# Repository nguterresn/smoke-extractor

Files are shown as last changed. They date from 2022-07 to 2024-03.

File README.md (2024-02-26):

# Welcome to the Smoke Extractor Repository!

Are you tired of inhaling smoke and fumes while soldering? Look no further! This portable smoke extractor is here to evolve your soldering experience.

This repository contains all the information you need to build your own smoke extractor using readily available components.

| [PCB](https://github.com/nguterresn/smoke-extractor/tree/master/pcb/1v1) | [STL](https://github.com/nguterresn/smoke-extractor/tree/master/stl) | [GERBER](https://github.com/nguterresn/smoke-extractor/blob/master/pcb/1v1/jlcpcb/production_files/GERBER-smoke_extractorV1_1.zip) | [BOM](https://github.com/nguterresn/smoke-extractor/blob/master/pcb/1v1/jlcpcb/production_files/BOM-smoke_extractorV1_1.csv) |
|-----|-----|---|-----|

Below is a list of what you need. Let's start with the PCB:

* Take the [Bill of Materials](https://github.com/nguterresn/smoke-extractor/blob/master/pcb/1v1/jlcpcb/production_files/BOM-smoke_extractorV1_1.csv) and order from [LCSC](https://www.lcsc.com).
* Take the [compressed gerber files](https://github.com/nguterresn/smoke-extractor/blob/master/pcb/1v1/jlcpcb/production_files/GERBER-smoke_extractorV1_1.zip) and order the PCB from [JLCPCB](https://jlcpcb.com)

To 3D print the [enclosure](https://github.com/nguterresn/smoke-extractor/tree/master/stl/1v1), I would recommend to print it vertically with supports only where the PCB fits and at the top.

* You can find the files for the enclosure at [Thinginverse](https://www.thingiverse.com/thing:6496883) or on the [repository](https://github.com/nguterresn/smoke-extractor/tree/master/stl/1v1).
* You can find the sliced model and ready to print file for BambuLab printers here.

And finally, necessary items you can find in Amazon:

* Buy the Fume's filter. I took a [filter used on cat litter boxes](https://www.amazon.se/gp/product/B07WJ1Y1CH/ref=ppx_yo_dt_b_asin_title_o08_s00?ie=UTF8&psc=1) and trimmed it to 80x80mm.
* Buy a [80x80x25mm 12V fan](https://www.amazon.se/-/en/1-06W-80x80x25mm-56-1m³-2600U-EE80251S31000U999/dp/B07ZBNZQ2S/ref=sr_1_3?crid=MVLR8KCZBU2A&dib=eyJ2IjoiMSJ9.yyIoiUBXEqPdx7PXhLvxQ6DgrM7XN99XWWnRf-wjLIC2jV-B3UQ4XywT_NGIYMAKHvOpfRhJtW1-Edui-ORV4xDNA9OV7_BThwgb9X33OIwgTvXAGk9CamoQANMFjjYQfQlXwd1fQ9uBfTSz37shrT1HXBxxIDawscOyjEqbqhflptzGCS32OoU-07Krv_tXsq_2aFJ8kRP7iFG2Fm3--l_kvcWPGcEGKE2OmgzGbOBmr5wPGlOs1hTMt8ZC6lYbEhc1kAilJPhcBsXh4ESUahyO5wKTHMeF1VTbrVZGBB4.kkiZ6oj-aX831UgWn2JdLQOQZ6zxw4aFCHIgBYpVpvM&dib_tag=se&keywords=fan+80x80+12v&qid=1708787756&sprefix=fan+80x80+12v%2Caps%2C92&sr=8-3). Any fan should suffice (as long as is within 80x80x25mm), however some fans are specially built for increased air flow and low noise, such as [Noctua ones](https://www.amazon.se/-/en/Noctua-NF-R8-Redux-1800-PWM-performance/dp/B00KF7MVI2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).
* Buy a [18350 battery holder from Amazon](https://www.amazon.se/-/en/3-7V-18650-Battery-Plastic-Storage/dp/B07MM1NHHL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).

Once you have received everything you ordered, I recommend to use an hot air gun or a soldering plate to solder the PCB.

After the soldering process, I recommended soldering the fan power cables into the 12V and GND pads on the PCB, such that the fan is left connected to the PCB.

Start by adding the fan into the top part and match with the bottom pins.
Place the PCB; use two M3-5mm screws to fix it if the PCB is loose.

The cables are hidden below the fan and behind the PCB.

To assemble the back lid you will also need 2x M3-5mm screws and 2x M3-10mm screws.

Happy soldering!

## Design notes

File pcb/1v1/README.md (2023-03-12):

On *CustomSymbols* - Project based symbols.

On *CustomFootprints* - Project based `.kicad_mod` footprints.

On *CustomSteps* - Project based `.step` files.

---

To add symbols to the project, open the file *CustomSymbols* (extension `.kicad_sym`) with a text editor and add the desired symbol as:

```md
(symbol "RA11131100" (in_bom yes) (on_board yes)
    (property "Reference" "U" (id 0) (at 0 0 0)
      (effects (font (size 1.27 1.27)))
    )
    (property "Value" "RA11131100" (id 1) (at 0 0 0)
      (effects (font (size 1.27 1.27)))
    )
    (property "Footprint" "" (id 2) (at 0 0 0)
      (effects (font (size 1.27 1.27)) hide)
    )
    (property "Datasheet" "" (id 3) (at 0 0 0)
      (effects (font (size 1.27 1.27)) hide)
    )
    (symbol "RA11131100_0_1"
      (rectangle (start -3.81 7.62) (end 3.81 2.54)
        (stroke (width 0.1524) (type default) (color 0 0 0 0))
        (fill (type none))
      )
      (arc (start -1.27 6.35) (mid -0.7022 5.0464) (end 0 3.81)
        (stroke (width 0.1524) (type default) (color 0 0 0 0))
        (fill (type none))
      )
    )
    (symbol "RA11131100_1_1"
      (pin power_in line (at -6.35 5.08 0) (length 2.54)
        (name "IN" (effects (font (size 1.27 1.27))))
        (number "1" (effects (font (size 1.27 1.27))))
      )
      (pin power_out line (at 6.35 5.08 180) (length 2.54)
        (name "OUT" (effects (font (size 1.27 1.27))))
        (number "2" (effects (font (size 1.27 1.27))))
      )
    )
)
``` 

The file `sym-lib-table` routes the project to the *CustomSymbols* folder.

---

To add footprints to the project, open the folder *CustomFootprints* and paste the desired `.kicad_mod` file.

The file `fp-lib-table` routes the project to the *CustomFootprints* folder.

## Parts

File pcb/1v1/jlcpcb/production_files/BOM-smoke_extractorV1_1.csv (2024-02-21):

Comment | Designator | Footprint | LCSC
4k7 | R13 | R_0603_1608Metric_Pad0.98x0.95mm_HandSolder | C105428
1.2k | R16 | R_0603_1608Metric_Pad0.98x0.95mm_HandSolder | C118396
TP4056 | U5 | SOP-8_3.9x4.9mm_P1.27mm | C16581
100 | R20 | R_0805_2012Metric_Pad1.20x1.40mm_HandSolder | C17408
5k1 | R10,R2,R22,R9 | R_0603_1608Metric_Pad0.98x0.95mm_HandSolder | C178023
Fuse | F1 | Fuse_0603_1608Metric_Pad1.05x0.95mm_HandSolder | C182303
10u | C6 | C_0603_1608Metric_Pad1.08x0.95mm_HandSolder | C19702
USB-TYPE-C-31-M-15 | U1 | USB-TYPE-C-31-M-15 | C223908
44.2k | R21 | R_0603_1608Metric_Pad0.98x0.95mm_HandSolder | C23056
ME2149FM5G | U7 | SOT-23-5_HandSoldering | C236786
SS14 | D10,D5 | D_SMA | C2480
FH8205 | U8 | SOT-23-6_Handsoldering | C2928988
3.3u | L1 | L_Wuerth_WE-PD2-Typ-MS | C2929417
10k | R5 | R_0603_1608Metric_Pad0.98x0.95mm_HandSolder | C2930027
3k3 | R1,R11,R12,R14,R15,R18,R7,R8 | R_0603_1608Metric_Pad0.98x0.95mm_HandSolder | C3017726
0.1u | C1,C2,C7 | C_0603_1608Metric_Pad1.08x0.95mm_HandSolder | C30926
1k | R3,R4,R6 | R_0603_1608Metric_Pad0.98x0.95mm_HandSolder | C328340
DW01A | IC1 | SOT-23-6_Handsoldering | C351410
SDDJE | U2 | SDDJE | C358626
FDN336P | Q1 | SOT-23 | C475693
LM324DT | U3 | SOIC127P600X175-14N | C71035
22u | C8 | C_0805_2012Metric_Pad1.18x1.45mm_HandSolder | C98190
TestPoint | TP2 | TestPoint_Pad_2.0x2.0mm
MountingHole_Pad | H2 | MountingHole_3.2mm_M3_ISO7380_Pad
YLED | D2 | LED_0603_1608Metric_Pad1.05x0.95mm_HandSolder
LED | D1 | LED_0603_1608Metric_Pad1.05x0.95mm_HandSolder
RLED | D7 | LED_0603_1608Metric_Pad1.05x0.95mm_HandSolder
GLED | D3 | LED_0603_1608Metric_Pad1.05x0.95mm_HandSolder
RLED | D9 | LED_0603_1608Metric_Pad1.05x0.95mm_HandSolder
MountingHole_Pad | H1 | MountingHole_3.2mm_M3_ISO7380_Pad
GLED | D8 | LED_0603_1608Metric_Pad1.05x0.95mm_HandSolder
SW_Push | SW1 | SW_PUSH_6mm
GLED | D4 | LED_0603_1608Metric_Pad1.05x0.95mm_HandSolder
Conn_01x01_Socket | J2 | TestPoint_Pad_2.5x2.5mm
Conn_01x01_Socket | J1 | TestPoint_Pad_2.5x2.5mm
18350-HOLDER | U6 | 18350-Holder

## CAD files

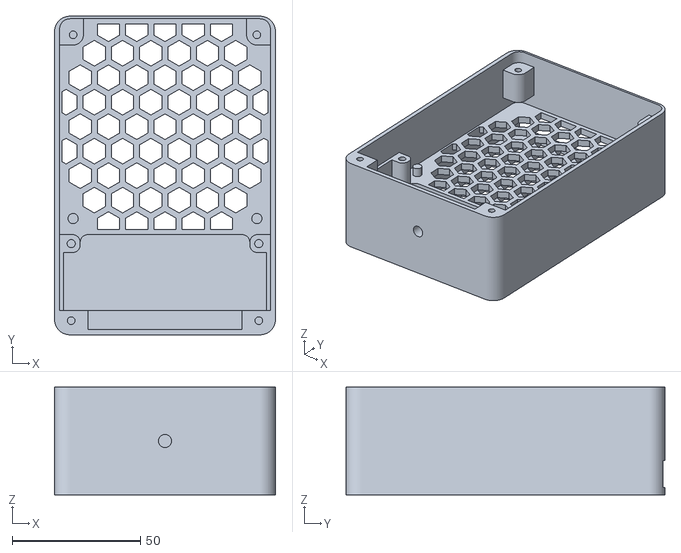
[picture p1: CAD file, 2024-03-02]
stl/Front.stl
86.0 x 124.0 x 42.0

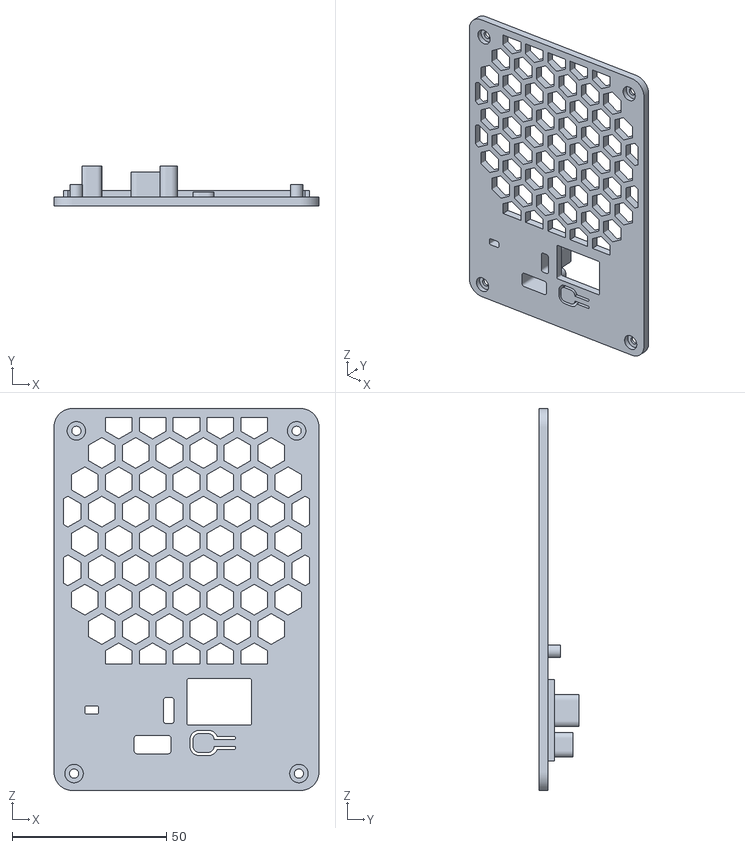
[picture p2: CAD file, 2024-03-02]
stl/BackLid.stl
86.0 x 13.0 x 124.0

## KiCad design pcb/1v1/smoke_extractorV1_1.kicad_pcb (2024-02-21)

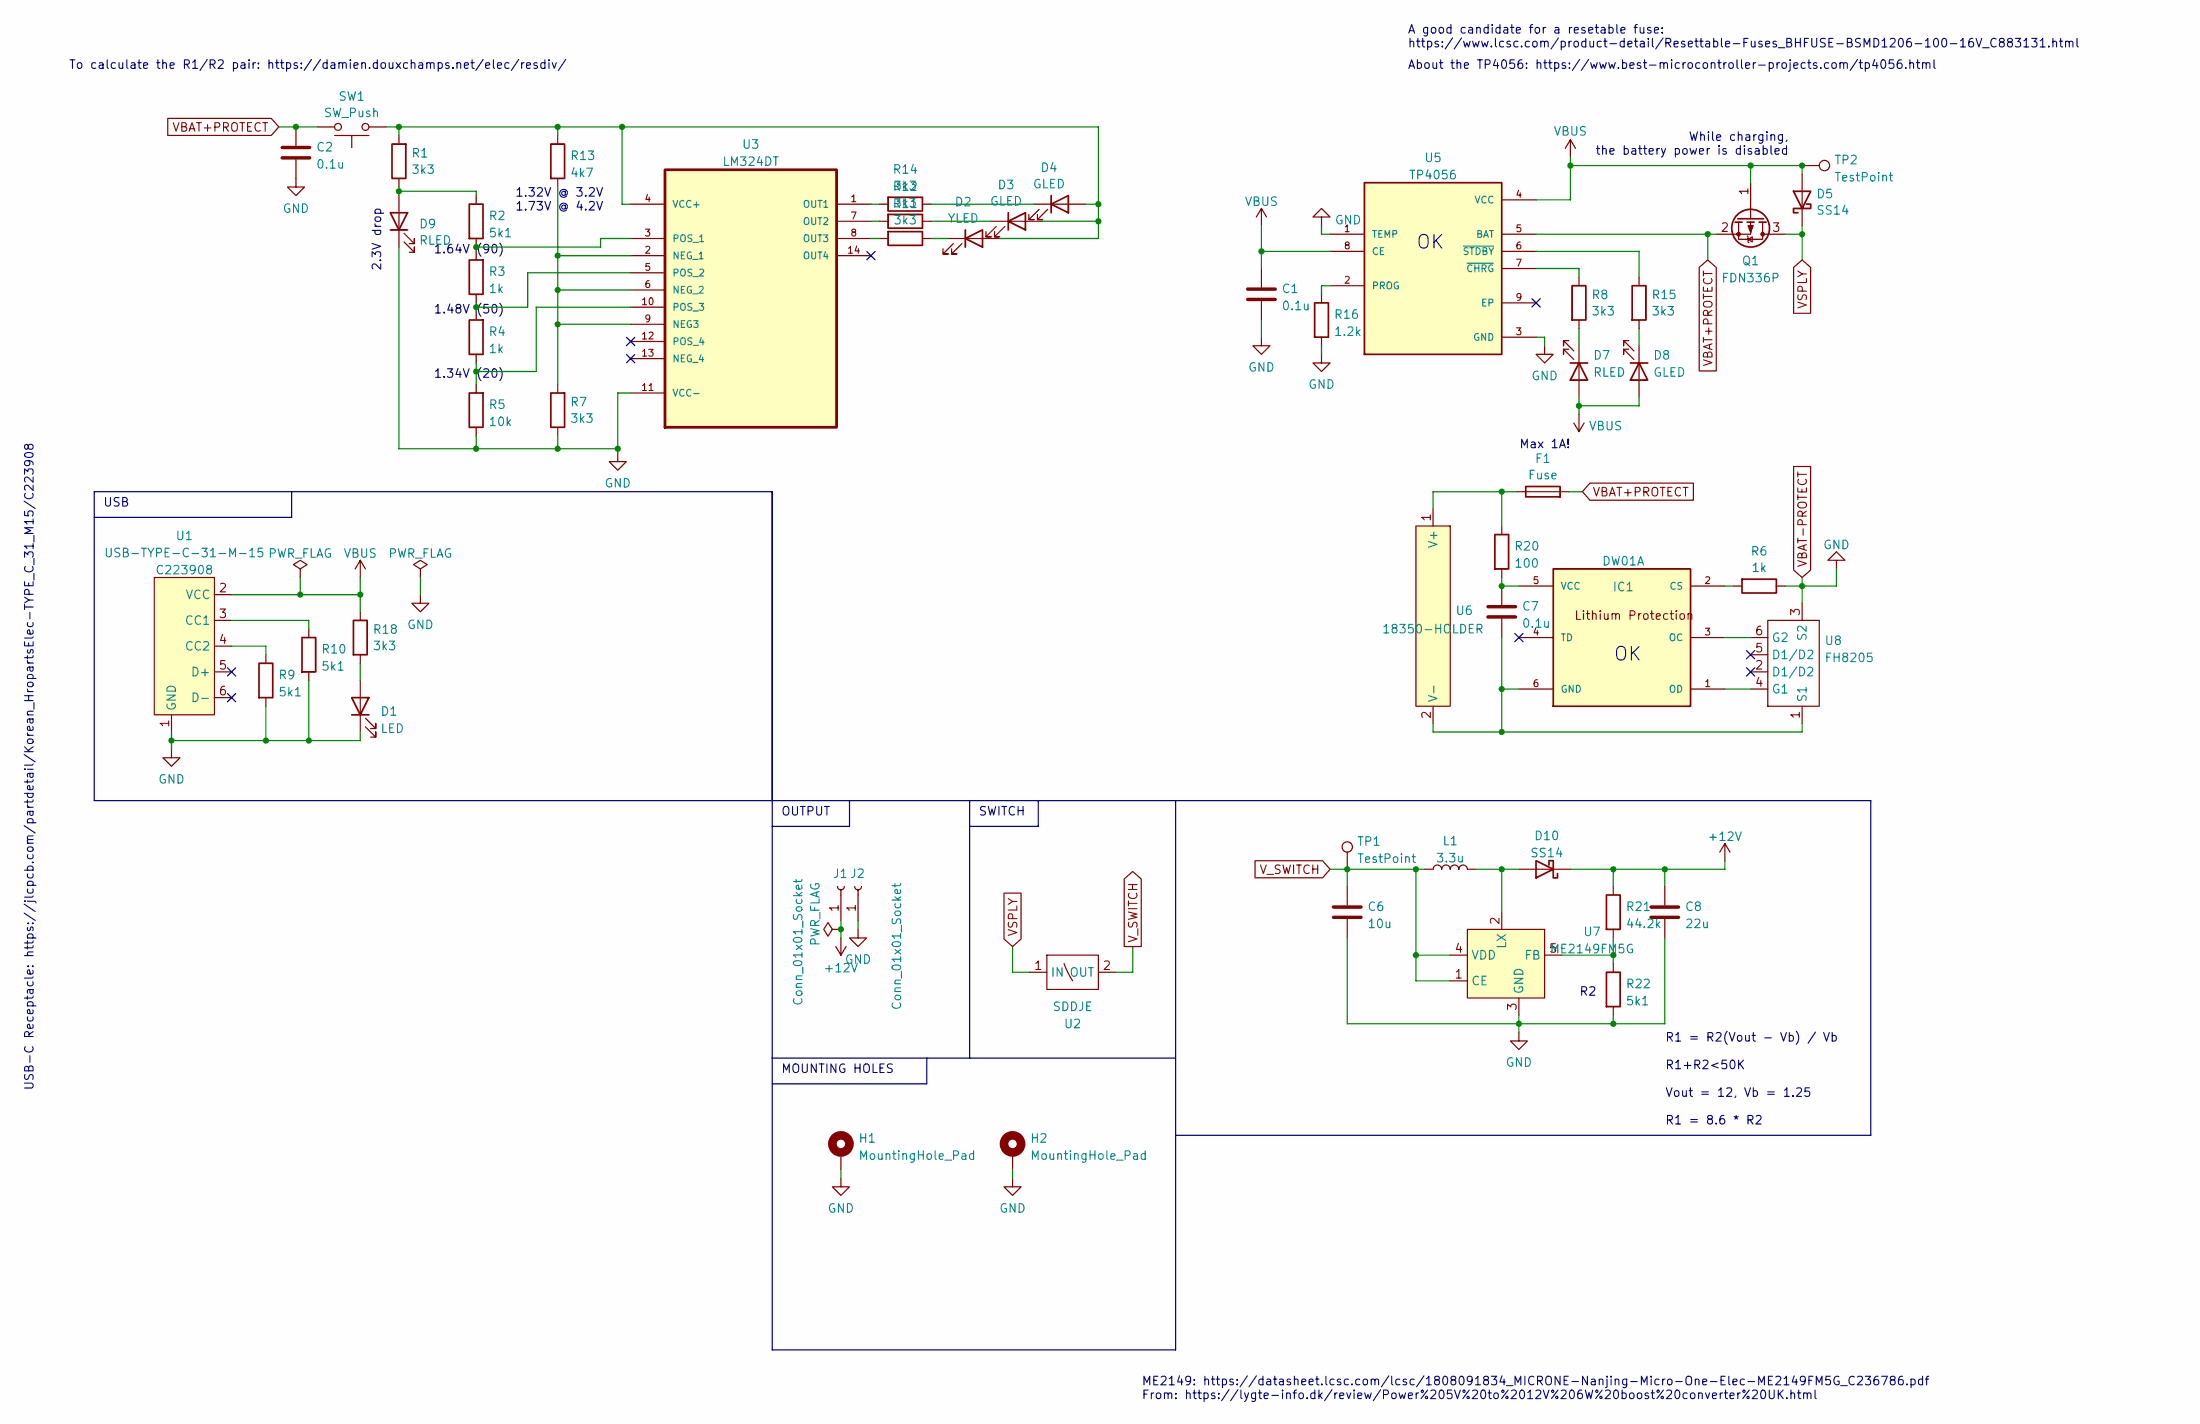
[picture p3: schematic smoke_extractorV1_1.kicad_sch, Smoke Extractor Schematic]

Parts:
C1, C2, C7: 0.1u; C_0603_1608Metric_Pad1.08x0.95mm_HandSolder; LCSC C30926
C6: 10u; C_0603_1608Metric_Pad1.08x0.95mm_HandSolder; LCSC C19702
C8: 22u; C_0805_2012Metric_Pad1.18x1.45mm_HandSolder; LCSC C98190
D1: LED; LED_0603_1608Metric_Pad1.05x0.95mm_HandSolder
D2: YLED; LED_0603_1608Metric_Pad1.05x0.95mm_HandSolder
D3, D4, D8: GLED; LED_0603_1608Metric_Pad1.05x0.95mm_HandSolder
D5, D10: SS14; D_SMA; LCSC C2480
D7, D9: RLED; LED_0603_1608Metric_Pad1.05x0.95mm_HandSolder
F1: Fuse; Fuse_0603_1608Metric_Pad1.05x0.95mm_HandSolder; LCSC C182303
H1, H2: MountingHole_Pad; MountingHole_3.2mm_M3_ISO7380_Pad
IC1: DW01A; SOT-23-6_Handsoldering; MPN DW01A; LCSC C351410
J1, J2: Conn_01x01_Socket; TestPoint_Pad_2.5x2.5mm
L1: 3.3u; L_Wuerth_WE-PD2-Typ-MS; LCSC C2929417
Q1: FDN336P; SOT-23; LCSC C475693
R1, R7, R8, R11, R12, R14, R15, R18: 3k3; R_0603_1608Metric_Pad0.98x0.95mm_HandSolder; LCSC C3017726
R2, R9, R10, R22: 5k1; R_0603_1608Metric_Pad0.98x0.95mm_HandSolder; LCSC C178023
R3, R4, R6: 1k; R_0603_1608Metric_Pad0.98x0.95mm_HandSolder; LCSC C328340
R5: 10k; R_0603_1608Metric_Pad0.98x0.95mm_HandSolder; LCSC C2930027
R13: 4k7; R_0603_1608Metric_Pad0.98x0.95mm_HandSolder; LCSC C105428
R16: 1.2k; R_0603_1608Metric_Pad0.98x0.95mm_HandSolder; LCSC C118396
R20: 100; R_0805_2012Metric_Pad1.20x1.40mm_HandSolder; LCSC C17408
R21: 44.2k; R_0603_1608Metric_Pad0.98x0.95mm_HandSolder; LCSC C23056
SW1: SW_Push; SW_PUSH_6mm
TP1, TP2: TestPoint; TestPoint_Pad_2.0x2.0mm
U1: USB-TYPE-C-31-M-15; LCSC C223908
U2: SDDJE; LCSC C358626
U3: LM324DT; SOIC127P600X175-14N; MPN LM324DT; LCSC C71035
U5: TP4056; SOP-8_3.9x4.9mm_P1.27mm; LCSC C16581
U6: 18350-HOLDER; 18350-Holder
U7: ME2149FM5G; SOT-23-5_HandSoldering; LCSC C236786
U8: FH8205; SOT-23-6_Handsoldering; LCSC C2928988

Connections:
+12V: C8.1, D10.1 (K), J1.1, R21.1
unnamed: D1.2 (A), R18.2
unnamed: D2.2 (A), D3.2 (A), D4.2 (A), R1.2, R13.1, SW1.1, U3.4 (VCC+)
unnamed: D2.1 (K), R11.1
unnamed: D3.1 (K), R12.1
unnamed: D4.1 (K), R14.1
unnamed: D7.1 (K), R8.2
unnamed: D8.1 (K), R15.2
unnamed: D9.2 (A), R1.1, R2.1
unnamed: D10.2 (A), L1.2, U7.2 (LX)
unnamed: IC1.2 (CS), R6.2
unnamed 11: C7.2, IC1.6 (GND), U6.2 (V-), U8.1 (S1); also elsewhere on the board
unnamed: IC1.3 (OC), U8.6 (G2)
unnamed: IC1.1 (OD), U8.4 (G1)
unnamed: C7.1, IC1.5 (VCC), R20.2
unnamed: R10.1, U1.3 (CC1)
unnamed: R9.1, U1.4 (CC2)
unnamed: R7.2, R13.2, U3.2 (NEG_1), U3.6 (NEG_2), U3.9 (NEG3)
unnamed: R14.2, U3.1 (OUT1)
unnamed: R12.2, U3.7 (OUT2)
unnamed: R11.2, U3.8 (OUT3)
unnamed: R2.2, R3.2, U3.3 (POS_1)
unnamed: R3.1, R4.2, U3.5 (POS_2)
unnamed: R4.1, R5.2, U3.10 (POS_3)
unnamed: R16.1, U5.2 (PROG)
unnamed: R8.1, U5.7 (~CHRG)
unnamed: R15.1, U5.6 (~STDBY)
unnamed 27: F1.1, R20.1, U6.1 (V+); also elsewhere on the board
unnamed: R21.2, R22.1, U7.5 (FB)
VBAT+PROTECT: C2.1, F1.2, Q1.2 (S), SW1.2, U5.5 (BAT)
VBAT-PROTECT: C1.2, C2.2, C6.2, C8.2, D1.1 (K), D9.1 (K), H1.1, H2.1, J2.1, R5.1, R6.1, R7.1, R9.2, R10.2, R16.2, R22.2, U1.1 (GND), U3.11 (VCC-), U5.1 (TEMP), U5.3 (GND), U7.3 (GND), U8.3 (S2)
VBUS: C1.1, D5.2 (A), D7.2 (A), D8.2 (A), Q1.1 (G), R18.1, TP2.1, U1.2 (VCC), U5.4 (VCC), U5.8 (CE)
VSPLY: D5.1 (K), Q1.3 (D), U2.1 (IN)
V_SWITCH: C6.1, L1.1, TP1.1, U2.2 (OUT), U7.1 (CE), U7.4 (VDD)

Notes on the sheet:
OUTPUT
1.32V @ 3.2V 1.73V @ 4.2V
2.3V drop
Max 1A!
A good candidate for a resetable fuse: https://www.lcsc.com/product-detail/Resettable-Fuses_BHFUSE-BSMD1206-100-16V_C883131.html
USB
About the TP4056: https://www.best-microcontroller-projects.com/tp4056.html
To calculate the R1/R2 pair: https://damien.douxchamps.net/elec/resdiv/
1.64V (90)
USB-C Receptacle: https://jlcpcb.com/partdetail/Korean_HropartsElec-TYPE_C_31_M15/C223908
MOUNTING HOLES
SWITCH
1.34V (20)
While charging, the battery power is disabled
1.48V (50)
R1 = R2(Vout - Vb) / Vb R1+R2<50K Vout = 12, Vb = 1.25 R1 = 8.6 * R2
ME2149: https://datasheet.lcsc.com/lcsc/1808091834_MICRONE-Nanjing-Micro-One-Elec-ME2149FM5G_C236786.pdf From: https://lygte-info.dk/review/Power%205V%20to%2012V%206W%20boost%20converter%20UK.html

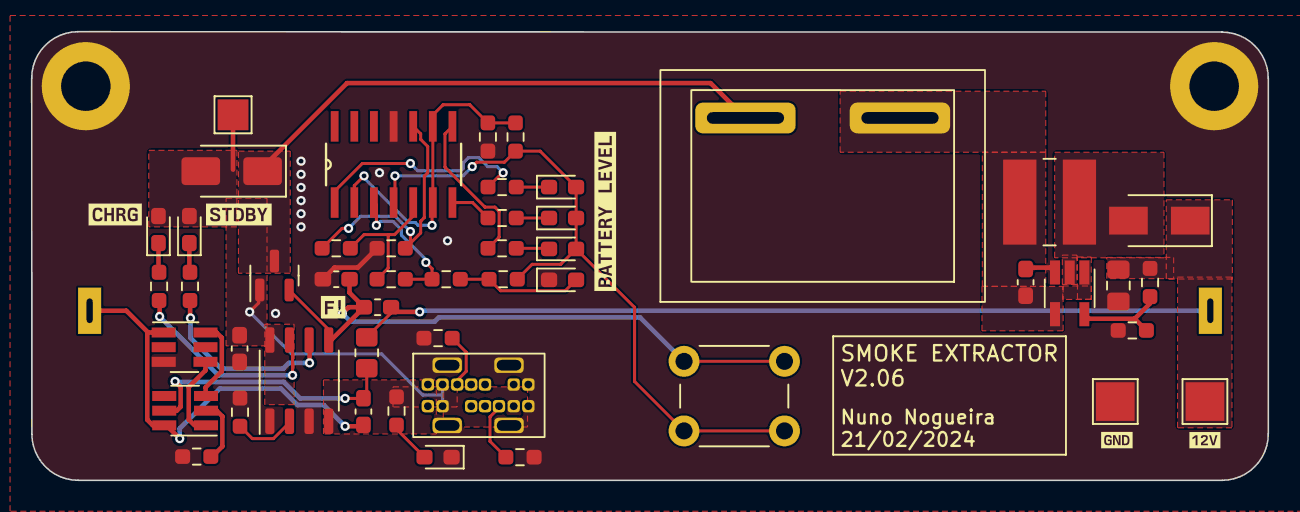
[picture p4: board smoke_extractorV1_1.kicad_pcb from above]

Board: 2 copper layers, 80.0 x 29.0 mm, 57 parts (1 on the bottom side), 34 nets.

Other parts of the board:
kibuzzard-65B168C9: G***; kibuzzard-65B168C9
kibuzzard-65B169C7: G***; kibuzzard-65B169C7
kibuzzard-65B1691E: G***; kibuzzard-65B1691E
kibuzzard-65B1692F: G***; kibuzzard-65B1692F
kibuzzard-655136D6: G***; kibuzzard-655136D6
kibuzzard-655136E2: G***; kibuzzard-655136E2
locked: 18350-HOLDER; 18350-Holder

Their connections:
unnamed 11: locked.2 (V-); also elsewhere on the board
unnamed 27: locked.1 (V+); also elsewhere on the board

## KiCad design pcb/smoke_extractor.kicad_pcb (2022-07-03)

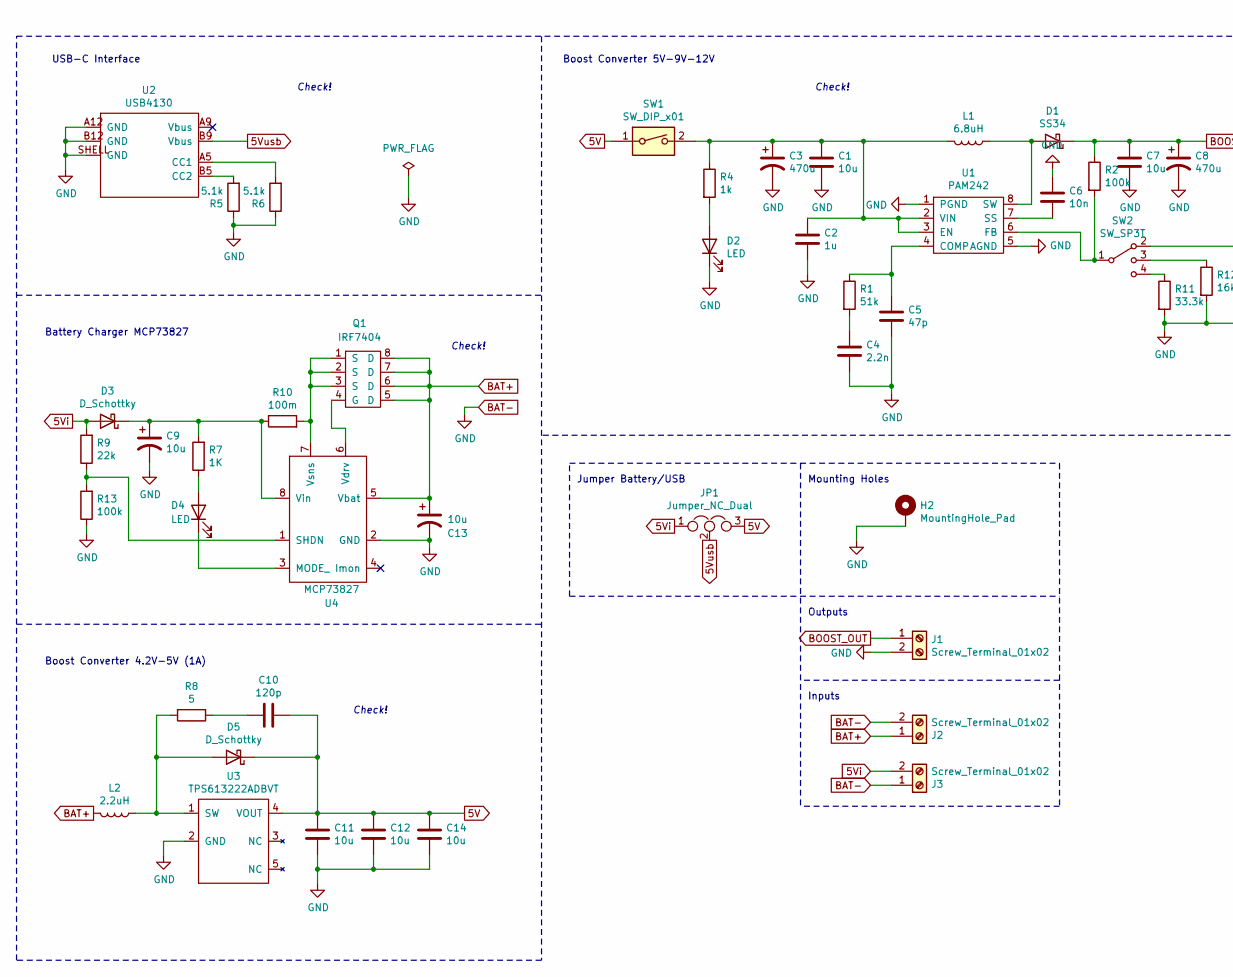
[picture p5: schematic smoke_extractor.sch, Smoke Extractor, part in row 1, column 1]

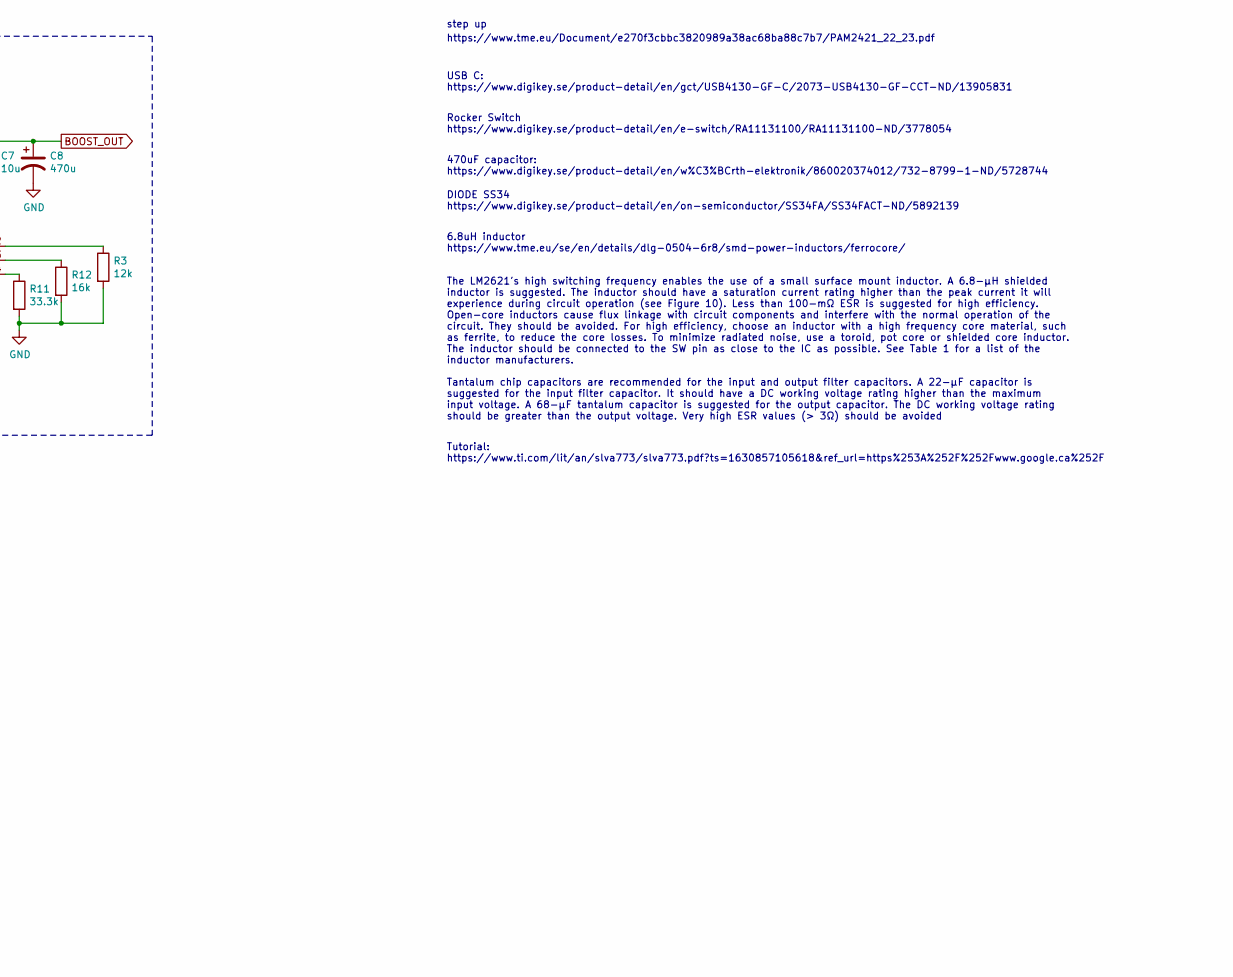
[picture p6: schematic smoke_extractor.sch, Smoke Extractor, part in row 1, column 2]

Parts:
C1, C7: 10u; C_0603_1608Metric_Pad1.08x0.95mm_HandSolder
C2: 1u; C_0603_1608Metric_Pad1.08x0.95mm_HandSolder
C3, C8: 470u; CP_Radial_D8.0mm_P3.50mm
C4: 2.2n; C_0603_1608Metric_Pad1.08x0.95mm_HandSolder
C5: 47p; C_0603_1608Metric_Pad1.08x0.95mm_HandSolder
C6: 10n; C_0603_1608Metric_Pad1.08x0.95mm_HandSolder
C9, C13: 10u; CP_Radial_D5.0mm_P2.50mm
C10: 120p; C_0603_1608Metric_Pad1.05x0.95mm_HandSolder
C11, C12, C14: 10u; C_0603_1608Metric_Pad1.05x0.95mm_HandSolder
D1: SS34; D_SOD-123F
D2, D4: LED; LED_0603_1608Metric_Pad1.05x0.95mm_HandSolder
D3, D5: D_Schottky; D_SMA_Handsoldering
H2: MountingHole_Pad; MountingHole_3.2mm_M3_Pad_Via
J1, J2, J3: Screw_Terminal_01x02; TerminalBlock_bornier-2_P5.08mm
JP1: Jumper_NC_Dual; PinHeader_1x03_P2.54mm_Vertical
L1: 6.8uH; BWVS004040186R8M00
L2: 2.2uH; L_1008_2520Metric
Q1: IRF7404; SOIC-8_3.9x4.9mm_P1.27mm
R1: 51k; R_0603_1608Metric_Pad0.98x0.95mm_HandSolder
R2: 100k; R_0603_1608Metric_Pad0.98x0.95mm_HandSolder
R3: 12k; R_0603_1608Metric_Pad0.98x0.95mm_HandSolder
R4: 1k; R_0603_1608Metric_Pad0.98x0.95mm_HandSolder
R5, R6: 5.1k; R_0603_1608Metric_Pad0.98x0.95mm_HandSolder
R7: 1K; R_0603_1608Metric_Pad1.05x0.95mm_HandSolder
R8: 5; R_0805_2012Metric_Pad1.15x1.40mm_HandSolder
R9: 22k; R_0603_1608Metric_Pad1.05x0.95mm_HandSolder
R10: 100m; R_2512_6332Metric_Pad1.52x3.35mm_HandSolder
R11: 33.3k; R_0603_1608Metric_Pad1.05x0.95mm_HandSolder
R12: 16k; R_0603_1608Metric_Pad1.05x0.95mm_HandSolder
R13: 100k; R_0603_1608Metric_Pad1.05x0.95mm_HandSolder
SW1: SW_DIP_x01; RA11131100
SW2: SW_SP3T; SP3T Slide
U1: PAM242; Diodes_SO-8EP
U2: USB4130
U3: TPS613222ADBVT; SOT-23-5_HandSoldering
U4: MCP73827; MSOP-8-1EP_3x3mm_P0.65mm_EP1.68x1.88mm

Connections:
5V: C10.1, C11.2, C12.2, C14.2, D5.1 (K), JP1.3, SW1.1, U3.4 (VOUT); also elsewhere on the board
5Vi: D3.2 (A), J3.2, JP1.1, R9.2; also elsewhere on the board
5Vusb: JP1.2, U2.B9 (Vbus); also elsewhere on the board
BAT+: C13.1, J2.1, L2.2, Q1.5 (D), Q1.6 (D), Q1.7 (D), Q1.8 (D), U4.5 (Vbat)
BAT-: C1.2, C2.2, C3.2, C4.2, C5.2, C6.2, C7.2, C8.2, C9.2, C11.1, C12.1, C13.2, C14.1, D2.1 (K), H2.1, J1.2, J2.2, J3.1, R3.2, R5.1, R6.1, R11.2, R12.2, R13.1, U1.1 (PGND), U1.5 (AGND), U1.9, U2.A12 (GND), U2.B12 (GND), U2.SHELL (GND), U3.2 (GND), U4.2 (GND); also elsewhere on the board
BOOST_OUT: C7.1, C8.1, D1.1 (K), J1.1, R2.1
unnamed: C1.1, C2.1, C3.1, L1.2, R4.1, SW1.2, U1.2 (VIN), U1.3 (EN)
unnamed: C4.1, R1.2
unnamed: C5.1, R1.1, U1.4 (COMP)
unnamed: C6.1, U1.7 (SS)
unnamed: C9.1, D3.1 (K), R7.2, R10.1, U4.8 (Vin)
unnamed: C10.2, R8.1
unnamed: D1.2 (A), L1.1, U1.8 (SW)
unnamed: D2.2 (A), R4.2
unnamed: D4.1 (K), U4.3 (MODE_)
unnamed: D4.2 (A), R7.1
unnamed: D5.2 (A), L2.1, R8.2, U3.1 (SW)
unnamed: Q1.1 (S), Q1.2 (S), Q1.3 (S), R10.2, U4.7 (Vsns)
unnamed: Q1.4 (G), U4.6 (Vdrv)
unnamed: R2.2, SW2.1, U1.6 (FB)
unnamed 20: R3.1, SW2.2; also elsewhere on the board
unnamed: R5.2, U2.B5 (CC2)
unnamed: R6.2, U2.A5 (CC1)
unnamed 23: R11.1, SW2.4; also elsewhere on the board
unnamed 24: R12.1, SW2.3; also elsewhere on the board
unnamed: R9.1, R13.2, U4.1 (SHDN)

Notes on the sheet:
https://www.tme.eu/Document/e270f3cbbc3820989a38ac68ba88c7b7/PAM2421_22_23.pdf
step up
USB C: https://www.digikey.se/product-detail/en/gct/USB4130-GF-C/2073-USB4130-GF-CCT-ND/13905831
Rocker Switch https://www.digikey.se/product-detail/en/e-switch/RA11131100/RA11131100-ND/3778054
470uF capacitor: https://www.digikey.se/product-detail/en/w%C3%BCrth-elektronik/860020374012/732-8799-1-ND/5728744
DIODE SS34 https://www.digikey.se/product-detail/en/on-semiconductor/SS34FA/SS34FACT-ND/5892139
The LM2621's high switching frequency enables the use of a small surface mount inductor. A 6.8-µH shielded inductor is suggested. The inductor should have a saturation current rating higher than the peak current it will experience during circuit operation (see Figure 10). Less than 100-mΩ ESR is su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
6.8uH inductor https://www.tme.eu/se/en/details/dlg-0504-6r8/smd-power-inductors/ferrocore/
Tantalum chip capacitors are recommended for the input and output filter capacitors. A 22-µF capacitor is suggested for the input filter capacitor. It should have a DC working voltage rating higher than the maximum input voltage. A 68-µF tantalum capacitor is suggested for the output capacitor. The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
Tutorial: https://www.ti.com/lit/an/slva773/slva773.pdf?ts=1630857105618&ref_url=https%253A%252F%252Fwww.google.ca%252F
USB-C Interface
Mounting Holes
Outputs
Boost Converter 5V-9V-12V
Boost Converter 4.2V-5V (1A)
Battery Charger MCP73827
Check!
Inputs
Jumper Battery/USB

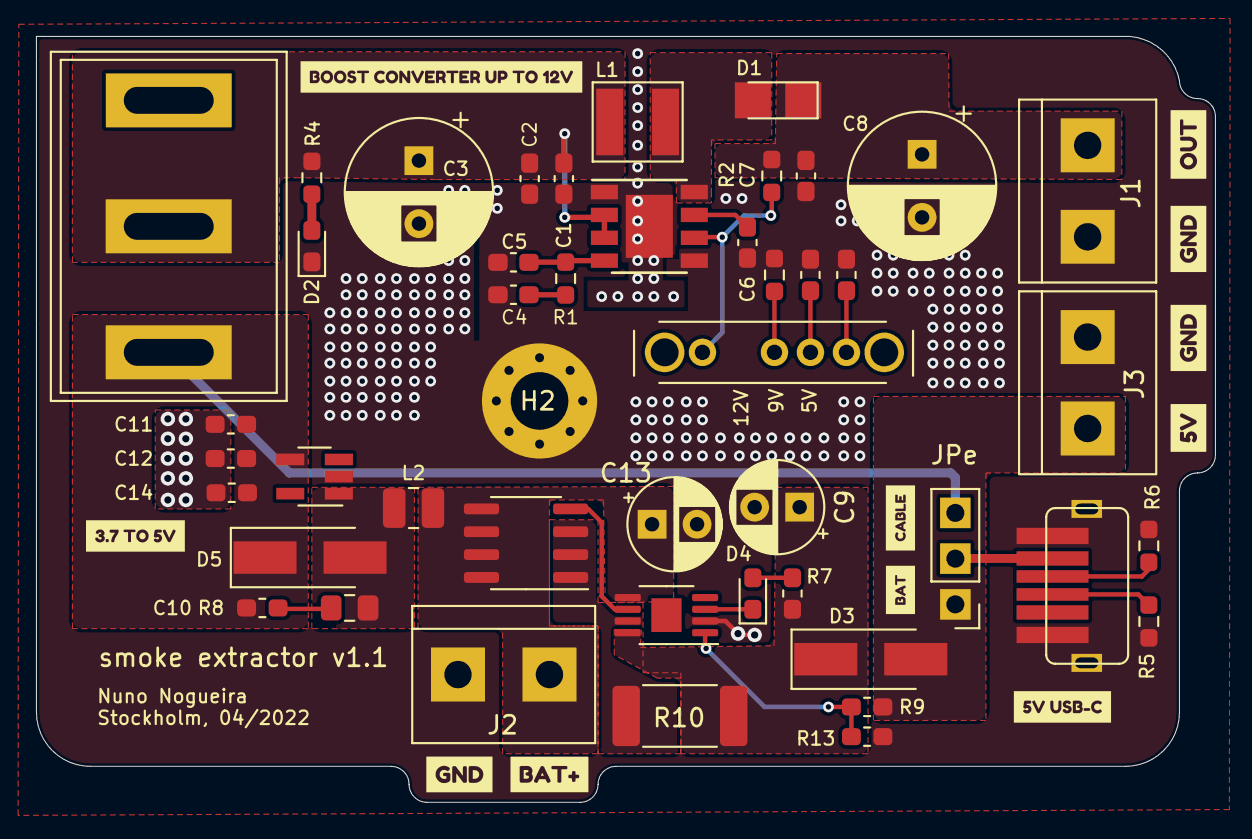
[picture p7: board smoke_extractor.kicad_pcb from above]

Board: 2 copper layers, 65.5 x 42.5 mm, 57 parts (0 on the bottom side), 26 nets.

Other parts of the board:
5V: 33.3k; R_0603_1608Metric_Pad1.05x0.95mm_HandSolder
9V: 16k; R_0603_1608Metric_Pad1.05x0.95mm_HandSolder
12V: 12k; R_0603_1608Metric_Pad0.98x0.95mm_HandSolder
JPe: Jumper_NC_Dual; PinHeader_1x03_P2.54mm_Vertical
kibuzzard-625C2F72, kibuzzard-625C2F72#2, kibuzzard-625C2F72#3, kibuzzard-625C2FA8, kibuzzard-625C2FDC, kibuzzard-625C30F5, kibuzzard-625C31B6, kibuzzard-625C31CC, kibuzzard-625C3009, kibuzzard-625C3140, kibuzzard-625C3168: G***; label

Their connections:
5V: JPe.3; also elsewhere on the board
5Vi: JPe.1; also elsewhere on the board
5Vusb: JPe.2; also elsewhere on the board
BAT-: 5V.2, 9V.2, 12V.2; also elsewhere on the board
unnamed 20: 12V.1; also elsewhere on the board
unnamed 23: 5V.1; also elsewhere on the board
unnamed 24: 9V.1; also elsewhere on the board

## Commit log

2022-07-04 changed folders and started pcb design all over again
    [smoke_extractor-B_Cu.gbr, smoke_extractor-B_Mask.gbr, smoke_extractor-B_Paste.gbr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]
2022-07-11 New smoke extractor version. WIP
    [smoke_extractorV1_1.kicad_pcb, smoke_extractorV1_1.kicad_sch]
2022-07-13 Added the first comparator for the USB Data lines
    [smoke_extractorV1_1.kicad_sch]
2022-07-13 Added comparators circuit (D lines and CC lines) to the schematic
    [smoke_extractorV1_1.kicad_sch]
2022-07-13 Added missing comparator for the CC2 line.
    [smoke_extractorV1_1.kicad_sch]
2022-07-13 Added a comment
    [smoke_extractorV1_1.kicad_sch]
2022-07-16 Added boost symbol + circuit
    [smoke_extractorV1_1.kicad_sch]
2022-07-16 Final schematics tweaks and BOM
    [smoke_extractorV1_1.kicad_sch]
2022-07-17 Ready to start designing!
    [smoke_extractorV1_1.kicad_pcb, smoke_extractorV1_1.kicad_sch]
2022-07-17 Added overvoltage IC
    [smoke_extractorV1_1.kicad_sch]
2022-07-20 Some more improvements. First idea of design (traces and zones still missing)
    Also need to:
    - Change the USB C to a horizontal footprint
    - Use an extended switch with screw terminal
    [smoke_extractorV1_1.kicad_pcb, smoke_extractorV1_1.kicad_sch]
2022-07-26 More improvements in the pcb design
    [smoke_extractorV1_1.kicad_pcb]
2022-07-28 Removed the voltage IC and one mounting hole. Missing boost converter conns only.
    [smoke_extractorV1_1.kicad_pcb, smoke_extractorV1_1.kicad_sch]
2022-07-30 Ready to place the order.
    [smoke_extractorV1_1.kicad_pcb]
2022-07-30 Error checks.
    [smoke_extractorV1_1.kicad_pcb]
2022-07-30 Exported gerber
    [smoke_extractorV1_1-B_Cu.gbr, smoke_extractorV1_1-B_Mask.gbr, smoke_extractorV1_1-B_Paste.gbr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]
2022-08-02 Schematic as pdf
    [smoke_extractorV1_1.kicad_sch]
2022-08-03 Reorganized repo
    [smoke_extractor-B_Cu.gbr, smoke_extractor-B_Mask.gbr, smoke_extractor-B_Paste.gbr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]
2022-08-03 Removed old images.
    [back.stl, box.stl, front.stl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]
2022-08-13 Added BOM
    [smoke_extractorV1_1.csv]
2022-09-10 Version 1.2
    [smoke_extractorV1_1.csv, smoke_extractorV1_1.kicad_pcb, smoke_extractorV1_1.kicad_sch]
2022-09-10 Added testing pads for version 1.2
    [smoke_extractorV1_1.kicad_pcb]
2022-09-29 Updated gerber files.
    [smoke_extractorV1_1-B_Cu.gbr, smoke_extractorV1_1-B_Mask.gbr, smoke_extractorV1_1-B_Paste.gbr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]
2022-10-09 Added stl files.
    [back.stl, front.stl, mid.stl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]
2022-10-16 Created latest bom
2023-01-26 Updated stls.
    [back.stl, mid.stl]
2023-01-29 added with-battery designs
    [back.stl, front.stl, mid.stl]
2023-01-31 Changed folder name.
    [smoke_extractorV1_1-B_Cu.gbr, smoke_extractorV1_1-B_Mask.gbr, smoke_extractorV1_1-B_Paste.gbr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]
2023-03-12 smoke extractor 2.0
    [back.stl, front.stl, mid.stl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]
2023-05-06 cleaned a bit
    [back.stl, front.stl, mid.stl]
2023-05-06 version 2.01 ready to order
    [smoke_extractorV1_1.csv, smoke_extractorV1_1.kicad_pcb, smoke_extractorV1_1.kicad_sch]
2023-11-30 version 2,03 and 2.04!
    [smoke_extractorV1_1-B_Cu.gbr, smoke_extractorV1_1-B_Mask.gbr, smoke_extractorV1_1-B_Paste.gbr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]
2024-01-04 new version 2.04
    [smoke_extractorV1_1-B_Cu.gbr, smoke_extractorV1_1-B_Mask.gbr, smoke_extractorV1_1-B_Paste.gbr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]
2024-01-24 Version 2.05
    [smoke_extractor2V04.step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]
2024-02-21 Removed some files and so one
    [BackLid.stl, back.stl, front.stl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]
2024-02-21 more changes.
    [BOM-smoke_extractorV1_1.csv, BackLid.stl, Front.stl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]
2024-02-26 last stl
    [BackLid.stl, Front.stl]
2024-03-02 support for Noctua NF-R8 redux-1800
    [BackLid.stl, Front.stl]
